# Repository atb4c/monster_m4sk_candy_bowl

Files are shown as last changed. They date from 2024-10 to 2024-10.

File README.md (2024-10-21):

# monster_m4sk_candy_bowl
Using Adafruit's Monster M4SK for a Halloween candy bowl.

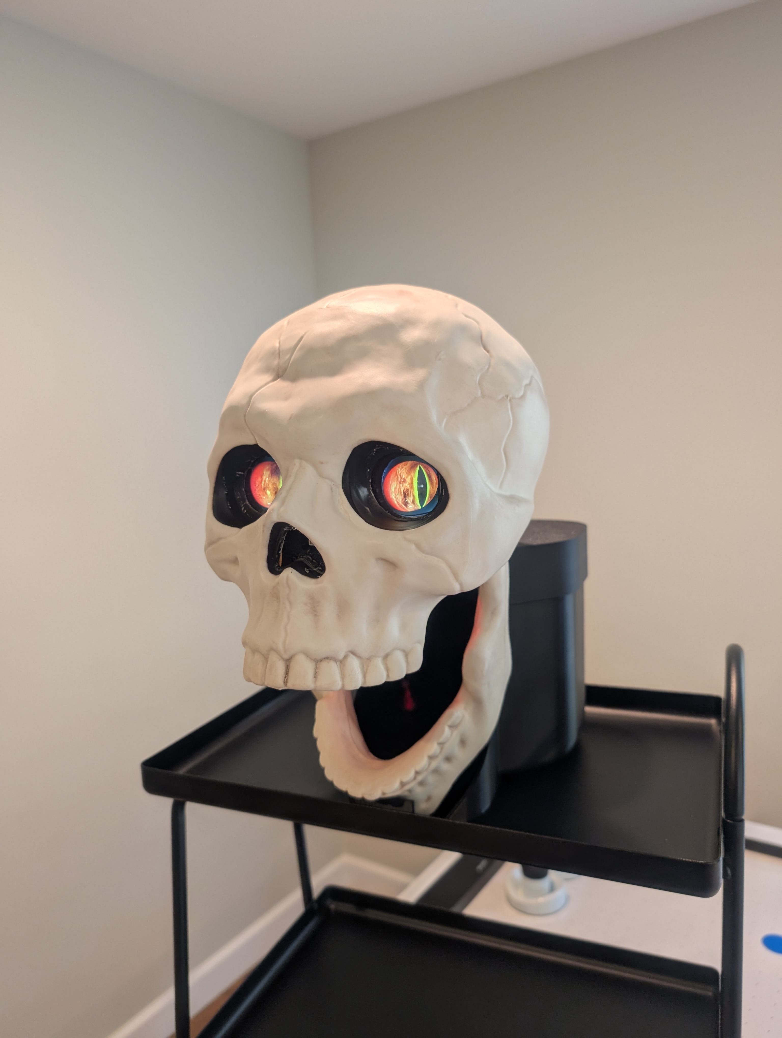
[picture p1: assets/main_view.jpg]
Monster M4SK Candy Bowl

[DEMO VIDEO](assets/demo.mp4)

This was modified from [THIS](https://learn.adafruit.com/monster-m4sk-is-watching-you/overview) project which uses a thermal camera to make the eyes follow you.  I added the ability to play detect when a hand is reached into the candy bowl along with playing audio clips (growling when a person is seen and a roar when a hand is being reached in).

I used [VSCode](https://code.visualstudio.com/) and [platformio](https://platformio.org/), but this could just as easily be done with the Arduino IDE.

Please follow the instructions [HERE](https://learn.adafruit.com/adafruit-monster-m4sk-eyes) to generally setup your Monster M4SK for building from source.

I have included the [EYE Config File](config.eye) I used here as well.

The plastic parts were printed on a BambuLabs P1S.  If you have a similar printer, you should be able to use the 3MF to print everything easily.

## Parts List

1. [Monster M4SK](https://www.adafruit.com/product/4343)
2. [Eye Lenses](https://www.adafruit.com/product/3917)
3. [Eye Connector Cable](https://www.adafruit.com/product/4350)
4. [Lithium Battery](https://www.adafruit.com/product/1781)
5. [Thermal Camera Cable](https://www.adafruit.com/product/3950)
6. [AMG8833 Thermal Camera](https://www.adafruit.com/product/3538)
7. [QT Connector Cable](https://www.adafruit.com/product/4210)
8. [APDS9960 Proximity Sensor](https://www.adafruit.com/product/3595)
9. [Mini-Speaker](https://www.adafruit.com/product/3923)
10. [3-Pin Connector](https://www.adafruit.com/product/3893)
11. [Neopixel LED Stick](https://www.adafruit.com/product/1426)
12. 10-in Skull to mount everything into.  I got mine at a Spirit Halloween, but these look like the same one [LINK1](https://www.tractorsupply.com/tsc/product/red-shed-large-light-up-skull-decoration-2352173?store=1922) [LINK2](https://partyconnexion.com/new-skull-lu-10/)
13. Optional: switch for easy on/off [LINK1](https://www.digikey.com/en/products/detail/e-switch/RA1113112R/3778055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)
14. M2.5 Nylon Screws - I recommend buying [THIS](https://www.adafruit.com/product/3299)

## Instructions

1. Use a dremel tool to remove base of the skull just below where the jow bone connects.
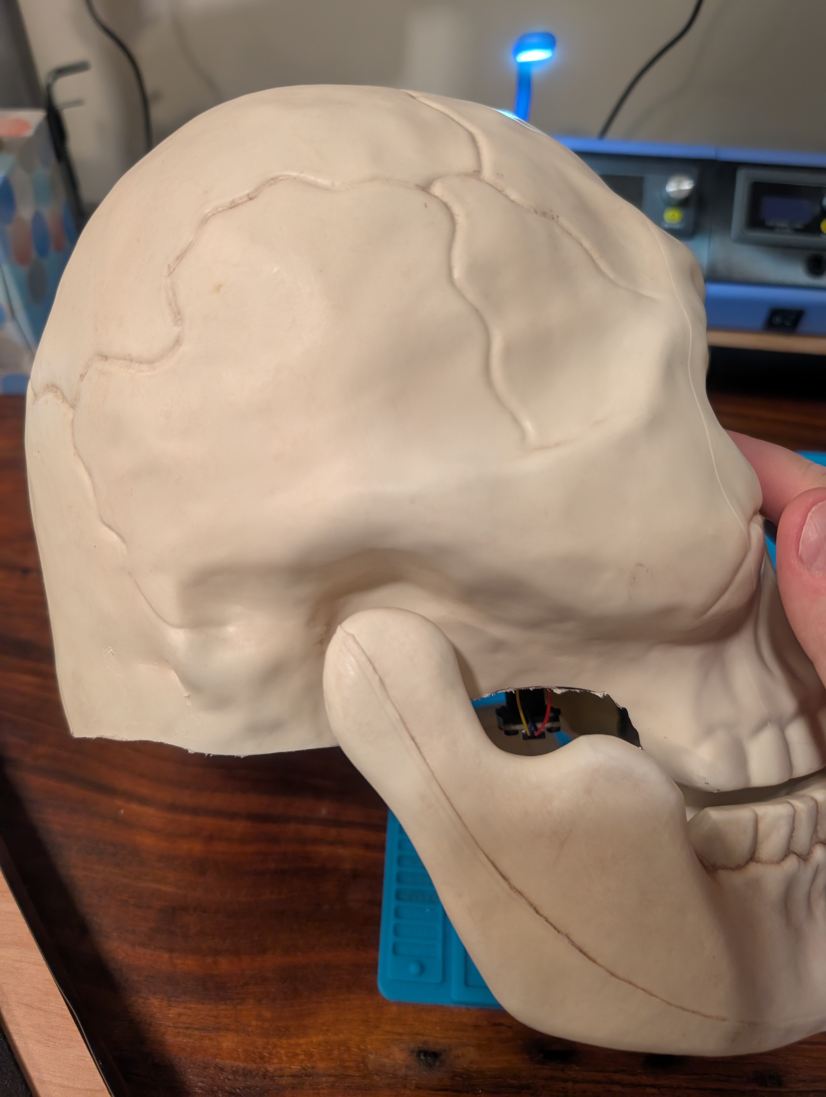
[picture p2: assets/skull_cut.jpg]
skull cutting

2. Once open, remove the light-up electronics from the kull (includes pieces connected to the eies and nose locations).
3. Assemble all the internal plastic pieces as shown here using super glue only if needed after press-fitting
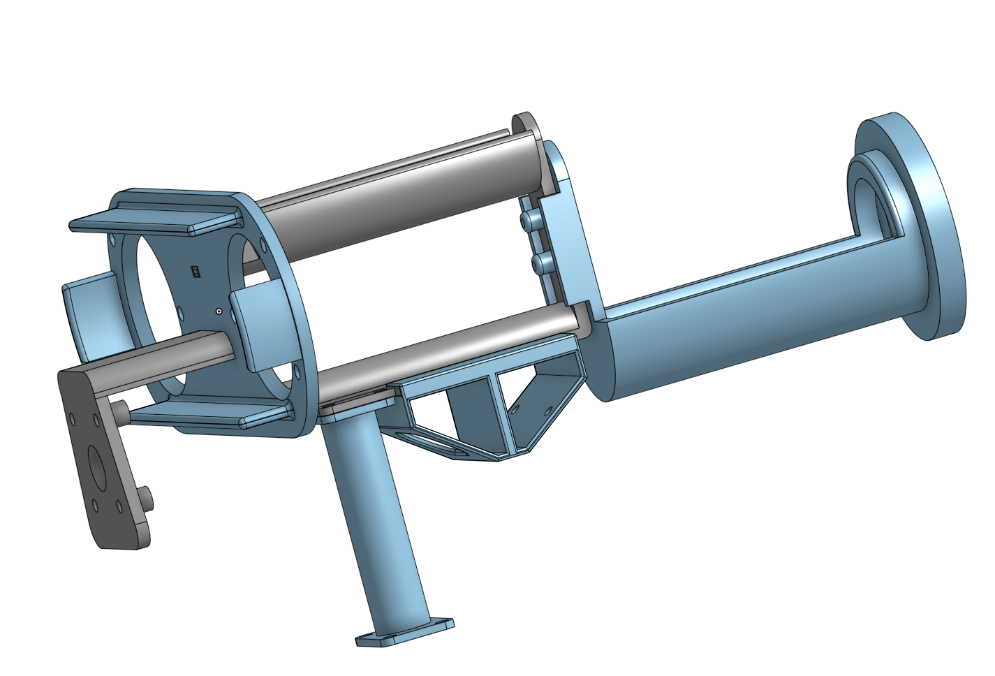
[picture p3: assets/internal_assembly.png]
internal plastic assembly

4. Attach electronics to the internal pieces
5. slide full internal assembly into skull.  It should hold in-place by the front and back pushing against the plastic skull
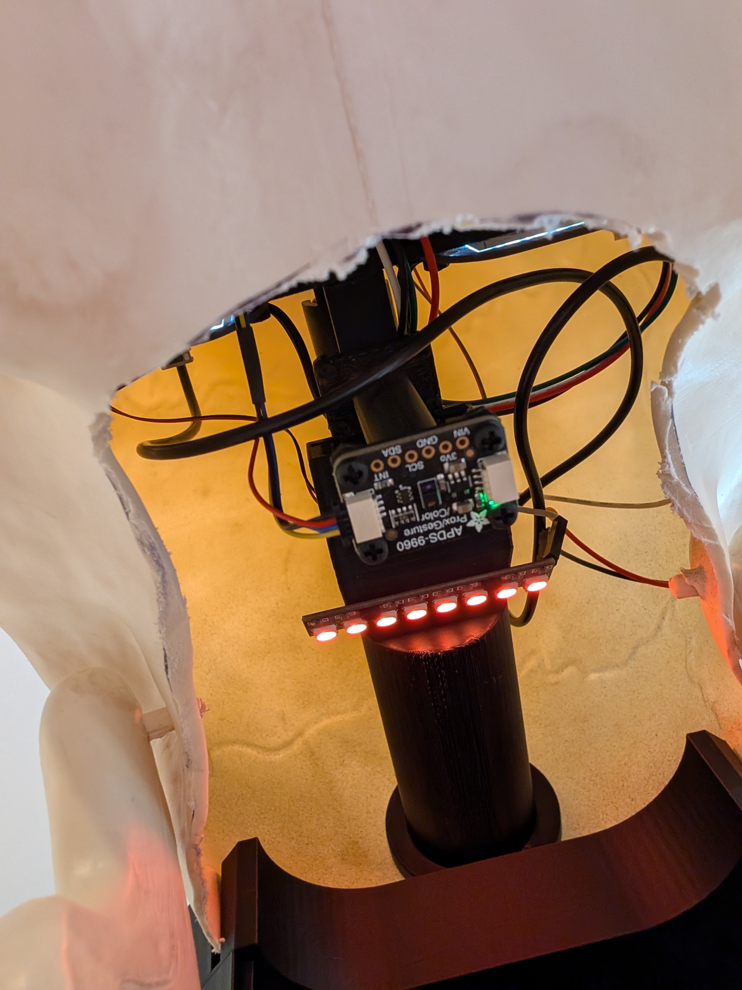
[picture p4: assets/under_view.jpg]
inside

6. Slide the back of the skull into the groove on the bown top
7. slide the skull and bowl top down onto the bowl making sure the jaw bone is open and held in-place by the bottom bracket on the bowl
8. Scare some kids... ;-)

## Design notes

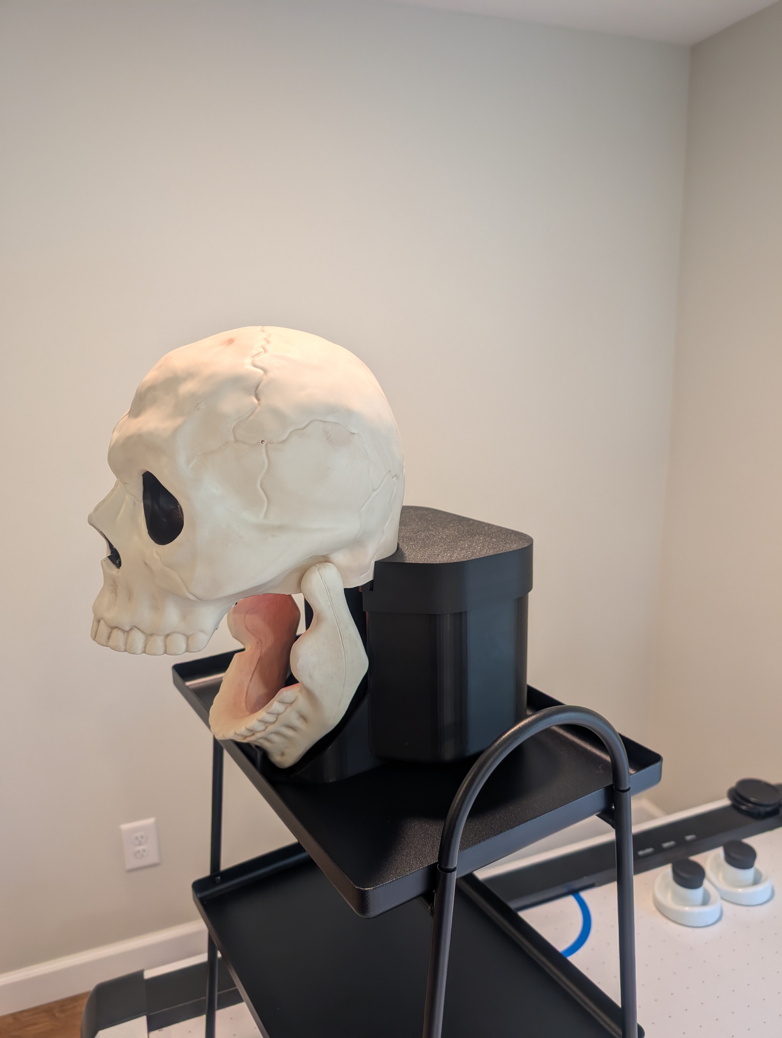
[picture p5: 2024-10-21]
assets/side_view.jpg

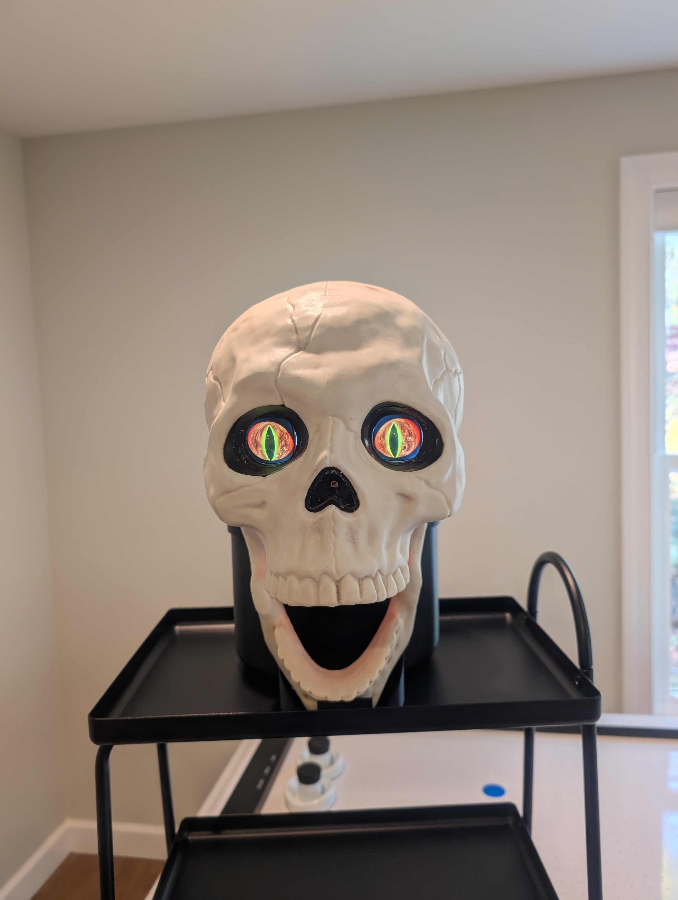
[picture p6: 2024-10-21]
assets/front_view.jpg

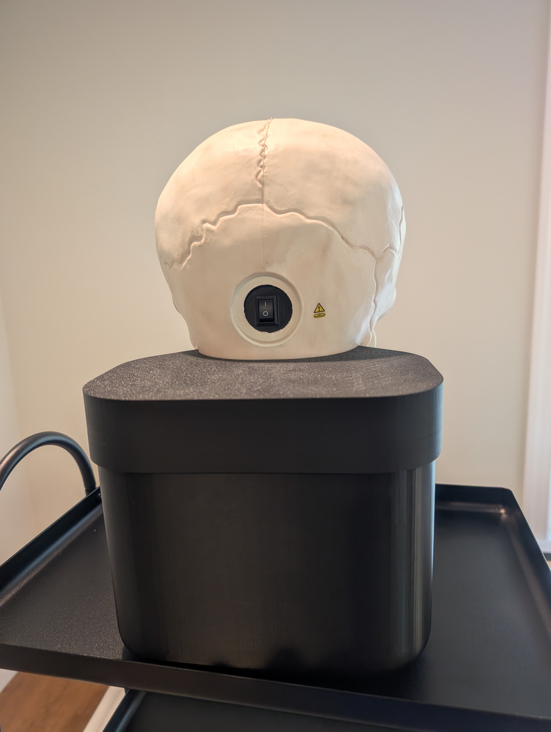
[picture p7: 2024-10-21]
assets/back_view.jpg

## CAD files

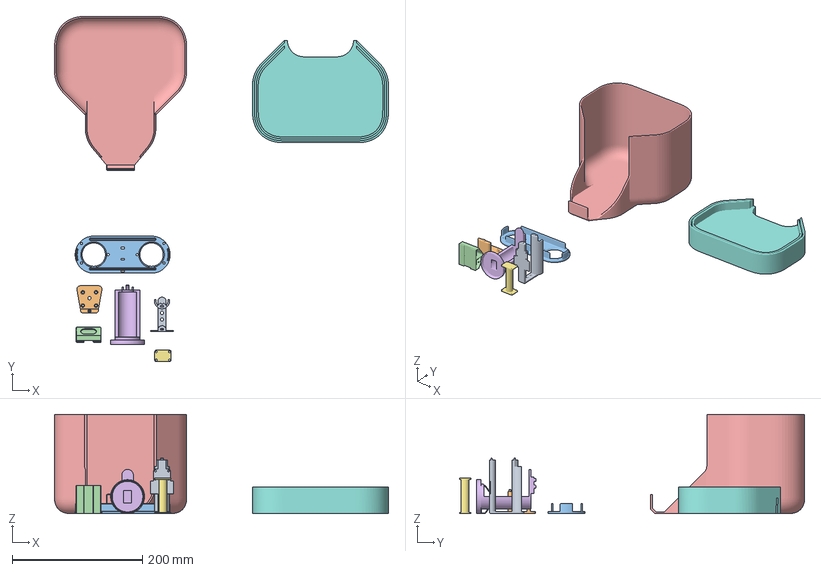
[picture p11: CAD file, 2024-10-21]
mechanicals/3MF/MonsterM4skCandyBowl.3mf
513.3 x 530.9 x 152.4 mm
m4sk_skull_back.stl
m4sk_skull_front (1).stl
m4sk_skull_middle (2).stl
speaker_LED_wedge.stl
bowl (4).stl
back_switch_holder (4).stl
proximity_extension (1).stl
bowl_top (5).stl

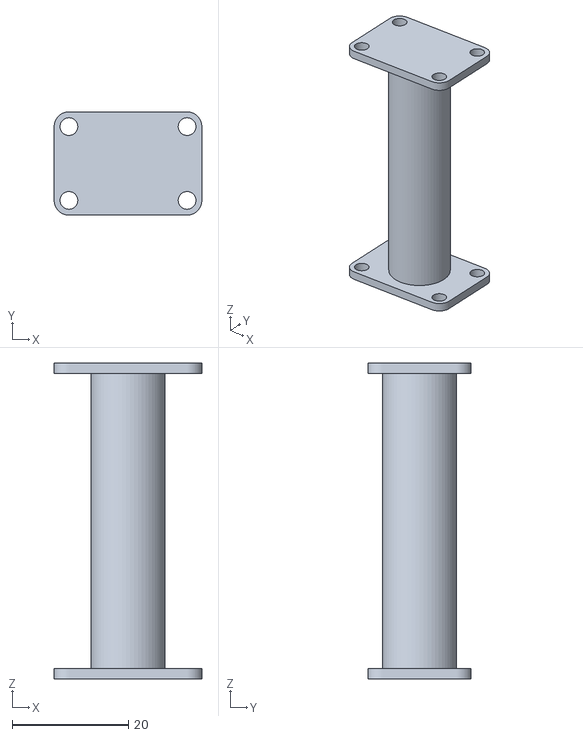
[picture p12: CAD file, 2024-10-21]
mechanicals/STL/proximity_extension.stl
25.4 x 17.8 x 54.4

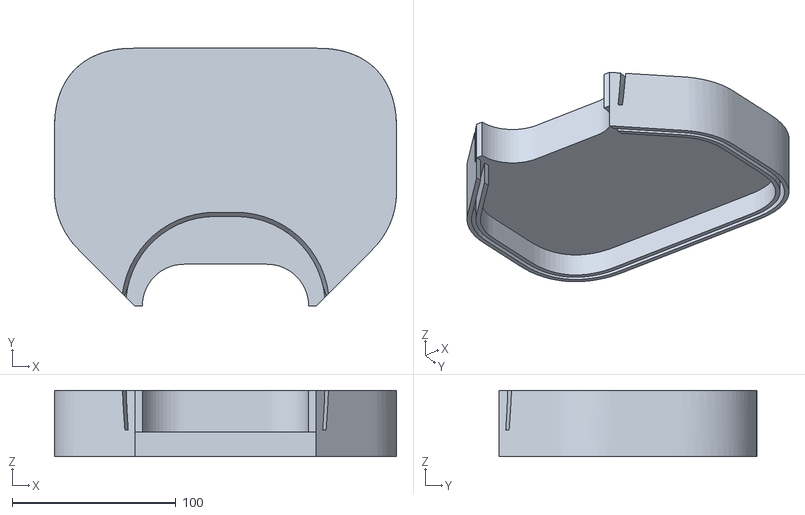
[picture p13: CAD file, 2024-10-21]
mechanicals/STL/bowl_top.stl
209.1 x 157.5 x 40.6

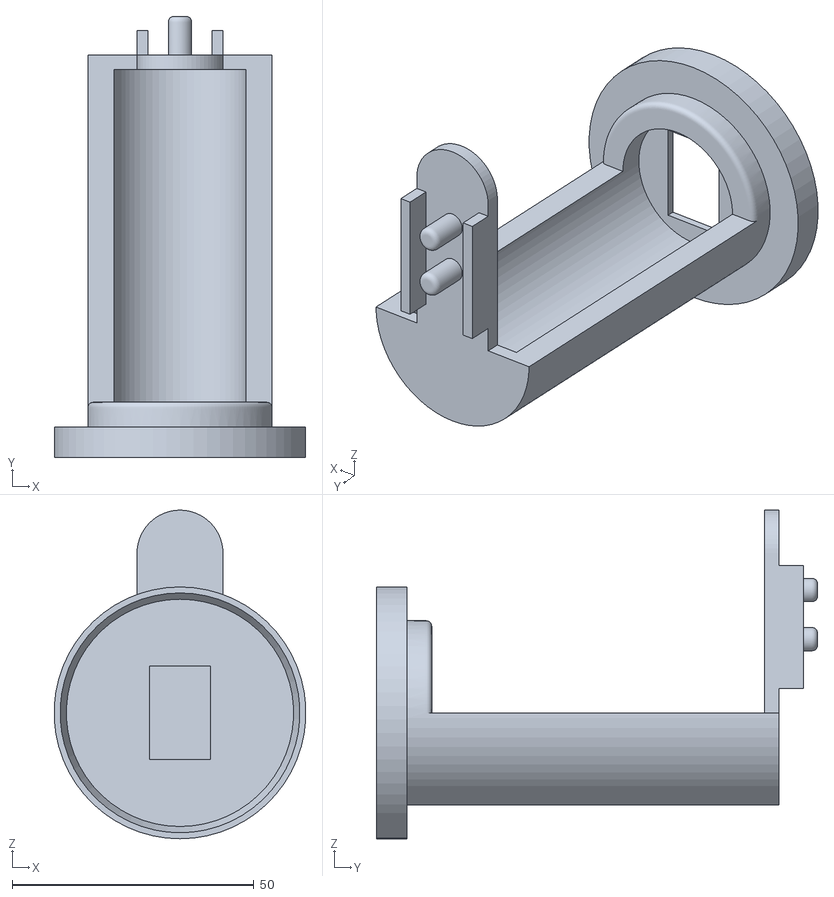
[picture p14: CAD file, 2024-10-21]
mechanicals/STL/back_switch_holder.stl
52.0 x 91.2 x 67.9

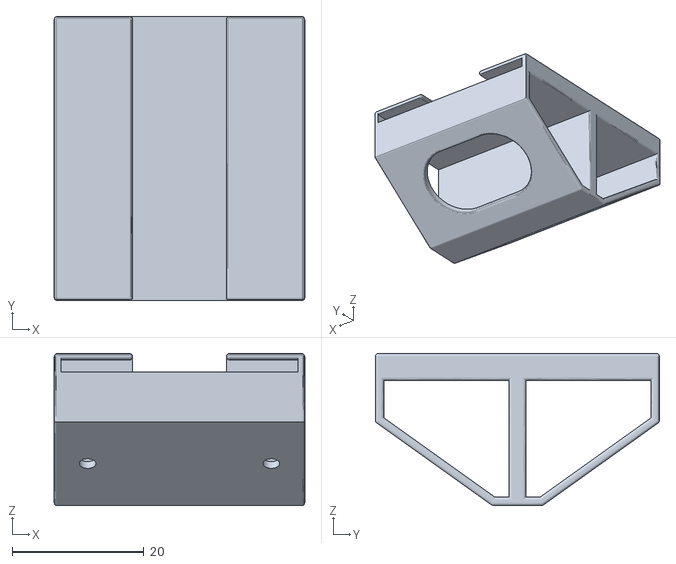
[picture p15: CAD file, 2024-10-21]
mechanicals/STL/speaker_LED_wedge.stl
38.1 x 43.2 x 23.1

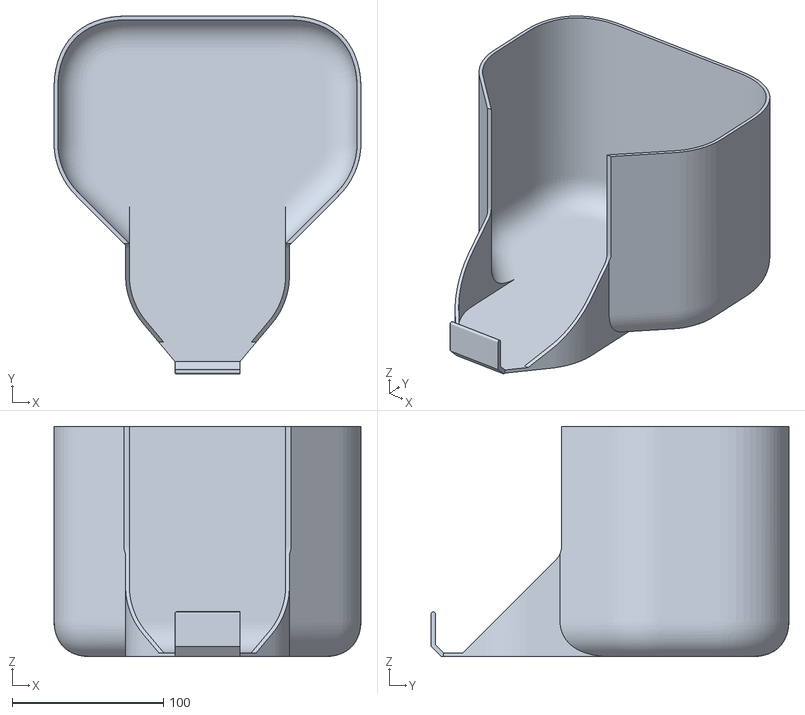
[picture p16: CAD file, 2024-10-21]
mechanicals/STL/bowl.stl
203.2 x 236.9 x 152.4

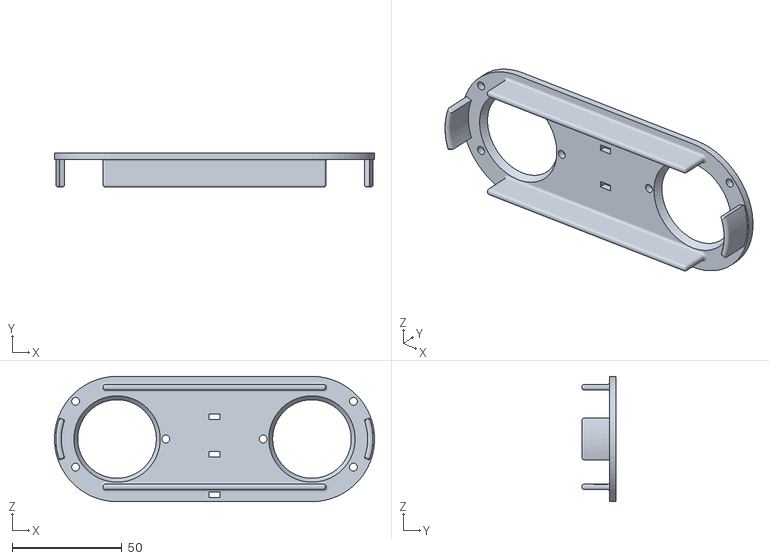
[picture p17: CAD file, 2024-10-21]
mechanicals/STL/m4sk_skull_middle.stl
146.0 x 15.6 x 57.1

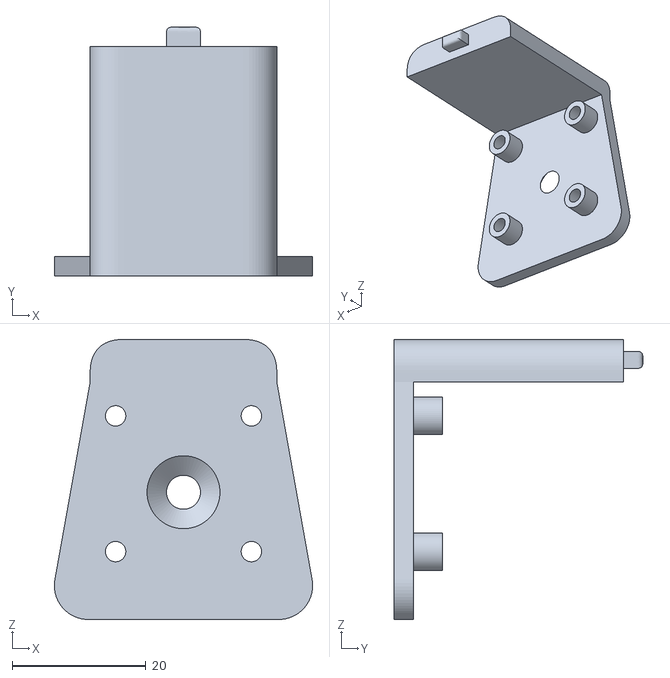
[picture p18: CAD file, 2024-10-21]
mechanicals/STL/m4sk_skull_front.stl
38.7 x 37.2 x 41.9

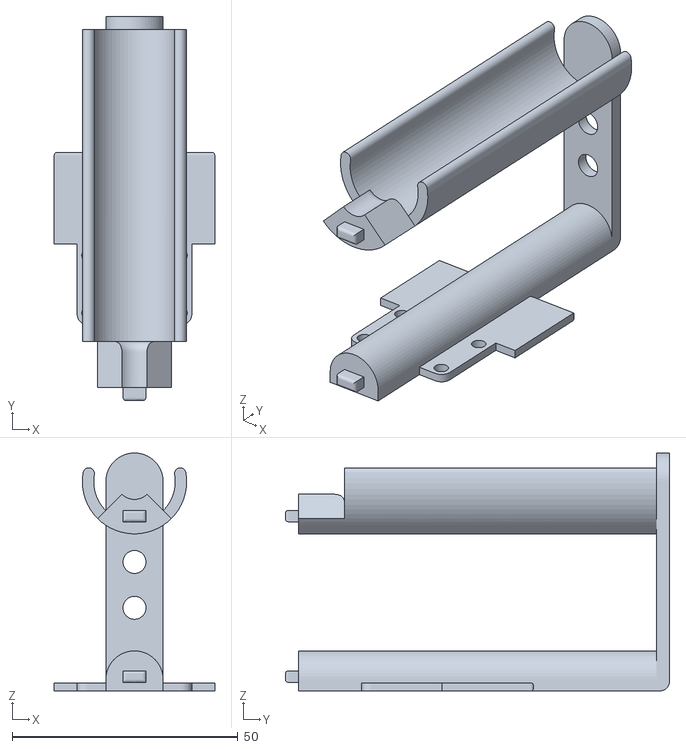
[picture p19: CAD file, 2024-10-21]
mechanicals/STL/m4sk_skull_back.stl
35.6 x 85.1 x 52.7

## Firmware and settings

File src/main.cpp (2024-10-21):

#include <Arduino.h>

// SPDX-FileCopyrightText: 2019 Phillip Burgess for Adafruit Industries
//
// SPDX-License-Identifier: MIT

// Animated eyes for Adafruit MONSTER M4SK and HALLOWING M4 dev boards.
// This code is pretty tightly coupled to the resources of these boards
// (one or two ST7789 240x240 pixel TFTs on separate SPI buses, and a
// SAMD51 microcontroller), and not as generally portable as the prior
// "Uncanny Eyes" project (better for SAMD21 chips or Teensy 3.X and
// 128x128 TFT or OLED screens, single SPI bus).

// IMPORTANT: in rare situations, a board may get "bricked" when running
// this code while simultaneously connected to USB. A quick-flashing status
// LED indicates the filesystem has gone corrupt. If this happens, install
// CircuitPython to reinitialize the filesystem, copy over your eye files
// (keep backups!), then re-upload this code. It seems to happen more often
// at high optimization settings (above -O3), but there's not 1:1 causality.
// The exact cause has not yet been found...possibly insufficient yield()
// calls, or some rare alignment in the Arcada library or USB-handling code.

// LET'S HAVE A WORD ABOUT COORDINATE SYSTEMS before continuing. From an
// outside observer's point of view, looking at the display(s) on these
// boards, the eyes are rendered COLUMN AT A TIME, working LEFT TO RIGHT,
// rather than the horizontal scanline order of Uncanny Eyes and most other
// graphics-heavy code. It was found much easier to animate the eyelids when
// working along this axis. A "column major" display is easily achieved by
// setting the screen(s) to ROTATION 3, which is a 90 degree
// counterclockwise rotation relative to the default. This places (0,0) at
// the BOTTOM-LEFT of the display, with +X being UP and +Y being RIGHT --
// so, conceptually, just swapping axes you have a traditional Cartesian
// coordinate system and trigonometric functions work As Intended, and the
// code tends to "think" that way in most places. Since the rotation is done
// in hardware though...from the display driver's point of view, one might
// think of these as "horizontal" "scanlines," and that the eye is being
// drawn sideways, with a left and right eyelid rather than bottom and top.
// Just mentioning it here because there may still be lingering comments
// and/or variables in the code where I refer to "scanlines" even though
// visually/spatially these are columns. Will do my best to comment local
// coordinate systems in different spots. (Any raster images loaded by
// Adafruit_ImageReader are referenced in typical +Y = DOWN order.)

// Oh also, "left eye" and "right eye" refer to the MONSTER'S left and
// right. From an observer's point of view, looking AT the monster, the
// "right eye" is on the left.

#if !defined(USE_TINYUSB)
  #error "Please select Tools->USB Stack->TinyUSB before compiling"
#endif

#define GLOBAL_VAR
#include "globals.h"

// Global eye state that applies to all eyes (not per-eye):
bool     eyeInMotion = false;
float    eyeOldX, eyeOldY, eyeNewX, eyeNewY;
uint32_t eyeMoveStartTime = 0L;
int32_t  eyeMoveDuration  = 0L;
uint32_t lastSaccadeStop  = 0L;
int32_t  saccadeInterval  = 0L;

// Some sloppy eye state stuff, some carried over from old eye code...
// kinda messy and badly named and will get cleaned up/moved/etc.
uint32_t timeOfLastBlink         = 0L,
         timeToNextBlink         = 0L;
int      xPositionOverMap        = 0;
int      yPositionOverMap        = 0;
uint8_t  eyeNum                  = 0;
uint32_t frames                  = 0;
uint32_t lastFrameRateReportTime = 0;
uint32_t lastLightReadTime       = 0;
float    lastLightValue          = 0.5;
double   irisValue               = 0.5;
int      iPupilFactor            = 42;
uint32_t boopSum                 = 0,
         boopSumFiltered         = 0;
bool     booped                  = false;
int      fixate                  = 7;
uint8_t  lightSensorFailCount    = 0;

// For autonomous iris scaling
#define  IRIS_LEVELS 7
float    iris_prev[IRIS_LEVELS] = { 0 };
float    iris_next[IRIS_LEVELS] = { 0 };
uint16_t iris_frame = 0;

// Callback invoked after each SPI DMA transfer - sets a flag indicating
// the next line of graphics can be issued as soon as its ready.
static void dma_callback(Adafruit_ZeroDMA *dma) {
  // It's possible to assign each DMA channel its own callback function
  // (freeing up a few cycles vs. this channel-to-eye lookup), but it's
  // written this way to scale to as many eyes as needed (up to one per
  // SERCOM if this is ported to something like Grand Central).
  for(uint8_t e=0; e<NUM_EYES; e++) {
    if(dma == &eye[e].dma) {
      eye[e].dma_busy = false;
      return;
    }
  }
}

// >50MHz SPI was fun but just too glitchy to rely on
//#if F_CPU < 200000000
// #define DISPLAY_FREQ   (F_CPU / 2)
// #define DISPLAY_CLKSRC SERCOM_CLOCK_SOURCE_FCPU
//#else
 #define DISPLAY_FREQ   50000000
 #define DISPLAY_CLKSRC SERCOM_CLOCK_SOURCE_100M
//#endif

SPISettings settings(DISPLAY_FREQ, MSBFIRST, SPI_MODE0);

// The time required to issue one scanline (DISPLAY_SIZE pixels x 16 bits) over
// SPI is a known(ish) quantity. The DMA scheduler isn't always perfectly
// deterministic though...especially on startup, as things make their way
// into caches. Very occasionally, something (not known yet) is causing
// SPI DMA to seize up. This condition is pretty easy to check for...
// periodically the code needs to wait on a DMA transfer to finish
// anyway, and we can use the micros() function to determine if it's taken
// considerably longer than expected (a factor of 4 is used - the "4000"
// below, to allow for caching/scheduling fudge). If so, that's our signal
// that something is likely amiss and we take evasive maneuvers, resetting
// the affected DMA channel (DMAbuddy::fix()).
#define DMA_TIMEOUT (uint32_t)((DISPLAY_SIZE * 16 * 4000) / (DISPLAY_FREQ / 1000))

static inline uint16_t readBoop(void) {
  uint16_t counter = 0;
  pinMode(boopPin, OUTPUT);
  digitalWrite(boopPin, HIGH);
  pinMode(boopPin, INPUT);
  while(digitalRead(boopPin) && (++counter < 1000));
  return counter;
}

// Crude error handler. Prints message to Serial Monitor, blinks LED.
void fatal(const char *message, uint16_t blinkDelay) {
  Serial.begin(9600);
  Serial.println(message);
  for(bool ledState = HIGH;; ledState = !ledState) {
    digitalWrite(LED_BUILTIN, ledState);
    delay(blinkDelay);
  }
}

#include <unistd.h> // sbrk() function

uint32_t availableRAM(void) {
  char top;                      // Local variable pushed on stack
  return &top - (char *)sbrk(0); // Top of stack minus end of heap
}

// SETUP FUNCTION - CALLED ONCE AT PROGRAM START ---------------------------

void setup() {
  if(!arcada.arcadaBegin())     fatal("Arcada init fail!", 100);
#if defined(USE_TINYUSB)
  if(!arcada.filesysBeginMSD()) fatal("No filesystem found!", 250);
#else
  if(!arcada.filesysBegin())    fatal("No filesystem found!", 250);
#endif

  // user_setup();

  arcada.displayBegin();

  // Backlight(s) off ASAP, they'll switch on after screen(s) init & clear
  arcada.setBacklight(0);

  DISPLAY_SIZE = min(ARCADA_TFT_WIDTH, ARCADA_TFT_HEIGHT);

  Serial.begin(115200);
  //while(!Serial) yield();

  user_setup();

  Serial.printf("Available RAM at start: %d\n", availableRAM());
  Serial.printf("Available flash at start: %d\n", arcada.availableFlash());
  yield(); // Periodic yield() makes sure mass storage filesystem stays alive

  // No file selector yet. In the meantime, you can override the default
  // config file by holding one of the 3 edge buttons at startup (loads
  // config1.eye, config2.eye or config3.eye instead). Keep fingers clear
  // of the nose booper when doing this...it self-calibrates on startup.
  // DO THIS BEFORE THE SPLASH SO IT DOESN'T REQUIRE A LENGTHY HOLD.
  char *filename = (char *)"config.eye";
 
  uint32_t buttonState = arcada.readButtons();
  if((buttonState & ARCADA_BUTTONMASK_UP) && arcada.exists("config1.eye")) {
    filename = (char *)"config1.eye";
  } else if((buttonState & ARCADA_BUTTONMASK_A) && arcada.exists("config2.eye")) {
    filename = (char *)"config2.eye";
  } else if((buttonState & ARCADA_BUTTONMASK_DOWN) && arcada.exists("config3.eye")) {
    filename = (char *)"config3.eye";
  }

  yield();
  // Initialize display(s)
#if (NUM_EYES > 1)
  eye[0].display = arcada._display;
  eye[1].display = arcada.display2;  
#else
  eye[0].display = arcada.display;
#endif

  // Initialize DMAs
  yield();
  uint8_t e;
  for(e=0; e<NUM_EYES; e++) {
#if (ARCADA_TFT_WIDTH != 160) && (ARCADA_TFT_HEIGHT != 128) // 160x128 is ST7735 which isn't able to deal
    eye[e].spi->setClockSource(DISPLAY_CLKSRC); // Accelerate SPI!
#endif
    eye[e].display->fillScreen(0);
    eye[e].dma.allocate();
    eye[e].dma.setTrigger(eye[e].spi->getDMAC_ID_TX());
    eye[e].dma.setAction(DMA_TRIGGER_ACTON_BEAT);
    eye[e].dptr = eye[e].dma.addDescriptor(NULL, NULL, 42, DMA_BEAT_SIZE_BYTE, false, false);
    eye[e].dma.setCallback(dma_callback);
    eye[e].dma.setPriority(DMA_PRIORITY_0);
    uint32_t spi_data_reg = (uint32_t)eye[e].spi->getDataRegister();
    for(int i=0; i<2; i++) {   // For each of 2 scanlines...
      for(int j=0; j<NUM_DESCRIPTORS; j++) { // For each descriptor on scanline...
        eye[e].column[i].descriptor[j].BTCTRL.bit.VALID    = true;
        eye[e].column[i].descriptor[j].BTCTRL.bit.EVOSEL   = DMA_EVENT_OUTPUT_DISABLE;
        eye[e].column[i].descriptor[j].BTCTRL.bit.BLOCKACT = DMA_BLOCK_ACTION_NOACT;
        eye[e].column[i].descriptor[j].BTCTRL.bit.BEATSIZE = DMA_BEAT_SIZE_BYTE;
        eye[e].column[i].descriptor[j].BTCTRL.bit.DSTINC   = 0;
        eye[e].column[i].descriptor[j].BTCTRL.bit.STEPSEL  = DMA_STEPSEL_SRC;
        eye[e].column[i].descriptor[j].BTCTRL.bit.STEPSIZE = DMA_ADDRESS_INCREMENT_STEP_SIZE_1;
        eye[e].column[i].descriptor[j].DSTADDR.reg         = spi_data_reg;
      }
    }
    eye[e].colNum       = DISPLAY_SIZE; // Force initial wraparound to first column
    eye[e].colIdx       = 0;
    eye[e].dma_busy     = false;
    eye[e].column_ready = false;
    eye[e].dmaStartTime = 0;

    // Default settings that can be overridden in config file
    eye[e].pupilColor        = 0x0000;
    eye[e].backColor         = 0xFFFF;
    eye[e].iris.color        = 0xFF01;
    eye[e].iris.data         = NULL;
    eye[e].iris.filename     = NULL;
    eye[e].iris.startAngle   = (e & 1) ? 512 : 0; // Rotate alternate eyes 180 degrees
    eye[e].iris.angle        = eye[e].iris.startAngle;
    eye[e].iris.mirror       = 0;
    eye[e].iris.spin         = 0.0;
    eye[e].iris.iSpin        = 0;
    eye[e].sclera.color      = 0xFFFF;
    eye[e].sclera.data       = NULL;
    eye[e].sclera.filename   = NULL;
    eye[e].sclera.startAngle = (e & 1) ? 512 : 0; // Rotate alternate eyes 180 degrees
    eye[e].sclera.angle      = eye[e].sclera.startAngle;
    eye[e].sclera.mirror     = 0;
    eye[e].sclera.spin       = 0.0;
    eye[e].sclera.iSpin      = 0;
    eye[e].rotation          = 3;

    // Uncanny eyes carryover stuff for now, all messy:
    eye[e].blink.state = NOBLINK;
    eye[e].blinkFactor = 0.0;
  }

  // SPLASH SCREEN (IF FILE PRESENT) ---------------------------------------

  yield();
  uint32_t startTime, elapsed;
  if (showSplashScreen) {
    showSplashScreen = ((arcada.drawBMP((char *)"/splash.bmp",
                         0, 0, eye[0].display)) == IMAGE_SUCCESS);
    if (showSplashScreen) { // Loaded OK?
      Serial.println("Splashing");
      if (NUM_EYES > 1) {   // Load on other eye too, ignore status
        yield();
        arcada.drawBMP((char *)"/splash.bmp", 0, 0, eye[1].display);
      }
      // Ramp up backlight over 1/2 sec duration
      startTime = millis();
      while ((elapsed = (millis() - startTime)) <= 500) {
        yield();
        arcada.setBacklight(255 * elapsed / 500);
      }
      arcada.setBacklight(255); // To the max
      startTime = millis();     // Note current time for backlight hold later
    }
  }

  // If no splash, or load failed, turn backlight on early so user gets a
  // little feedback, that the board is not locked up, just thinking.
  if (!showSplashScreen) arcada.setBacklight(255);

  // LOAD CONFIGURATION FILE -----------------------------------------------

  loadConfig(filename);

  // LOAD EYELIDS AND TEXTURE MAPS -----------------------------------------
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
void loop() {
  if(++eyeNum >= NUM_EYES) eyeNum = 0; // Cycle through eyes...

  uint8_t  x = eye[eyeNum].colNum;
  uint32_t t = micros();

  // If next column for this eye is not yet rendered...
  if(!eye[eyeNum].column_ready) {
    if(!x) { // If it's the first column...

      // ONCE-PER-FRAME EYE ANIMATION LOGIC HAPPENS HERE -------------------

      // Eye movement
      float eyeX, eyeY;
      if(moveEyesRandomly) {
        int32_t dt = t - eyeMoveStartTime;      // uS elapsed since last eye event
        if(eyeInMotion) {                       // Eye currently moving?
          if(dt >= eyeMoveDuration) {           // Time up?  Destination reached.
            eyeInMotion = false;                // Stop moving
            // The "move" duration temporarily becomes a hold duration...
            // Normally this is 35 ms to 1 sec, but don't exceed gazeMax setting
            uint32_t limit = min(1000000, gazeMax);
            eyeMoveDuration = random(35000, limit); // Time between microsaccades
            if(!saccadeInterval) {              // Cleared when "big" saccade finishes
              lastSaccadeStop = t;              // Time when saccade stopped
              saccadeInterval = random(eyeMoveDuration, gazeMax); // Next in 30ms to 3sec
            }
            // Similarly, the "move" start time becomes the "stop" starting time...
            eyeMoveStartTime = t;               // Save time of event
            eyeX = eyeOldX = eyeNewX;           // Save position
            eyeY = eyeOldY = eyeNewY;
          } else { // Move time's not yet fully elapsed -- interpolate position
            float e  = (float)dt / float(eyeMoveDuration); // 0.0 to 1.0 during move
            e = 3 * e * e - 2 * e * e * e; // Easing function: 3*e^2-2*e^3 0.0 to 1.0
            eyeX = eyeOldX + (eyeNewX - eyeOldX) * e; // Interp X
            eyeY = eyeOldY + (eyeNewY - eyeOldY) * e; // and Y
          }
        } else {                       // Eye is currently stopped
          eyeX = eyeOldX;
          eyeY = eyeOldY;
          if(dt > eyeMoveDuration) {   // Time up?  Begin new move.
            if((t - lastSaccadeStop) > saccadeInterval) { // Time for a "big" saccade
              // r is the radius in X and Y that the eye can go, from (0,0) in the center.
              float r = ((float)mapDiameter - (float)DISPLAY_SIZE * M_PI_2) * 0.75;
              eyeNewX = random(-r, r);
              float h = sqrt(r * r - eyeNewX * eyeNewX);
              eyeNewY = random(-h, h);
              // Set the duration for this move, and start it going.
              eyeMoveDuration = random(83000, 166000); // ~1/12 - ~1/6 sec
              saccadeInterval = 0; // Calc next interval when this one stops
            } else { // Microsaccade
              // r is possible radius of motion, ~1/10 size of full saccade.
              // We don't bother with clipping because if it strays just a little,
              // that's okay, it'll get put in-bounds on next full saccade.
              float r = (float)mapDiameter - (float)DISPLAY_SIZE * M_PI_2;
              r *= 0.07;
              float dx = random(-r, r);
              eyeNewX = eyeX - mapRadius + dx;
              float h = sqrt(r * r - dx * dx);
              eyeNewY = eyeY - mapRadius + random(-h, h);
              eyeMoveDuration = random(7000, 25000); // 7-25 ms microsaccade
            }
            eyeNewX += mapRadius;    // Translate new point into map space
            eyeNewY += mapRadius;
            eyeMoveStartTime = t;    // Save initial time of move
            eyeInMotion      = true; // Start move on next frame
          }
        }
      } else {
        // Allow user code to control eye position (e.g. IR sensor, joystick, etc.)
        float r = ((float)mapDiameter - (float)DISPLAY_SIZE * M_PI_2) * 0.9;
        eyeX = mapRadius + eyeTargetX * r;
        eyeY = mapRadius + eyeTargetY * r;
      }

      // Eyes fixate (are slightly crossed) -- amount is filtered for boops
      int nufix = booped ? 90 : 7;
      fixate = ((fixate * 15) + nufix) / 16;
      // save eye position to this eye's struct so it's same throughout render
      if(eyeNum & 1) eyeX += fixate; // Eyes converge slightly toward center
      else           eyeX -= fixate;
      eye[eyeNum].eyeX = eyeX;
      eye[eyeNum].eyeY = eyeY;

      // pupilFactor? irisValue? TO DO: pick a name and stick with it
      eye[eyeNum].pupilFactor = irisValue;
      // Also note - irisValue is calculated at the END of this function
      // for the next frame (because the sensor must be read when there's
      // no SPI traffic to the left eye)

      // Similar to the autonomous eye movement above -- blink start times
      // and durations are random (within ranges).
      if((t - timeOfLastBlink) >= timeToNextBlink) { // Start new blink?
        timeOfLastBlink = t;
        uint32_t blinkDuration = random(36000, 72000); // ~1/28 - ~1/14 sec
        // Set up durations for both eyes (if not already winking)
        for(uint8_t e=0; e<NUM_EYES; e++) {
          if(eye[e].blink.state == NOBLINK) {
            eye[e].blink.state     = ENBLINK;
            eye[e].blink.startTime = t;
            eye[e].blink.duration  = blinkDuration;
          }
        }
        timeToNextBlink = blinkDuration * 3 + random(4000000);
      }

      float uq, lq; // So many sloppy temp vars in here for now, sorry
      if(tracking) {
        // Eyelids naturally "track" the pupils (move up or down automatically)
        int ix = (int)map2screen(mapRadius - eye[eyeNum].eyeX) + (DISPLAY_SIZE/2), // Pupil position
            iy = (int)map2screen(mapRadius - eye[eyeNum].eyeY) + (DISPLAY_SIZE/2); // on screen
        iy += irisRadius * trackFactor;
        if(eyeNum & 1) ix = DISPLAY_SIZE - 1 - ix; // Flip for right eye
        if(iy > upperOpen[ix]) {
          uq = 1.0;
        } else if(iy < upperClosed[ix]) {
          uq = 0.0;
        } else {
          uq = (float)(iy - upperClosed[ix]) / (float)(upperOpen[ix] - upperClosed[ix]);
        }
        if(booped) {
          uq = 0.9;
          lq = 0.7;
        } else {
          lq = 1.0 - uq;
        }
      } else {
        // If no tracking, eye is FULLY OPEN when not blinking
        uq = 1.0;
        lq = 1.0;
      }
      // Dampen eyelid movements slightly
      // SAVE upper & lower lid factors per eye,
      // they need to stay consistent across frame
      eye[eyeNum].upperLidFactor = (eye[eyeNum].upperLidFactor * 0.6) + (uq * 0.4);
      eye[eyeNum].lowerLidFactor = (eye[eyeNum].lowerLidFactor * 0.6) + (lq * 0.4);

      // Process blinks
      if(eye[eyeNum].blink.state) { // Eye currently blinking?
        // Check if current blink state time has elapsed
        if((t - eye[eyeNum].blink.startTime) >= eye[eyeNum].blink.duration) {
          if(++eye[eyeNum].blink.state > DEBLINK) { // Deblinking finished?
            eye[eyeNum].blink.state = NOBLINK;      // No longer blinking
            eye[eyeNum].blinkFactor = 0.0;
          } else { // Advancing from ENBLINK to DEBLINK mode
            eye[eyeNum].blink.duration *= 2; // DEBLINK is 1/2 ENBLINK speed
            eye[eyeNum].blink.startTime = t;
            eye[eyeNum].blinkFactor = 1.0;
          }
        } else {
          eye[eyeNum].blinkFactor = (float)(t - eye[eyeNum].blink.startTime) / (float)eye[eyeNum].blink.duration;
          if(eye[eyeNum].blink.state == DEBLINK) eye[eyeNum].blinkFactor = 1.0 - eye[eyeNum].blinkFactor;
        }
      }

      // Periodically report frame rate. Really this is "total number of
      // eyeballs drawn." If there are two eyes, the overall refresh rate
      // of both screens is about 1/2 this.
      frames++;
      if(((t - lastFrameRateReportTime) >= 1000000) && t) { // Once per sec.
        Serial.println((frames * 1000) / (t / 1000));
        lastFrameRateReportTime = t;
      }

      // Once per frame (of eye #0), reset boopSum...
      if((eyeNum == 0) && (boopPin >= 0)) {
        boopSumFiltered = ((boopSumFiltered * 3) + boopSum) / 4;
        if(boopSumFiltered > boopThreshold) {
          if(!booped) {
            Serial.println("BOOP!");
          }
          booped = true;
        } else {
          booped = false;
        }
        boopSum = 0;
      }
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

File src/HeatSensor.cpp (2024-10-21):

// SPDX-FileCopyrightText: 2019 teejaydub for Adafruit Industries
//
// SPDX-License-Identifier: MIT

#if 1 // Change to 1 to enable this code (referenced by user_watch.cpp)
// CORRESPONDING LINE IN user_watch.cpp MUST ALSO BE ENABLED!

/* Read the IR sensor and try to figure out where the heat is located. 
*/
#include "HeatSensor.h"

#include <Wire.h>
#include <Adafruit_AMG88xx.h>

Adafruit_AMG88xx amg;

float pixels[AMG88xx_PIXEL_ARRAY_SIZE];

void HeatSensor::setup()
{
    x = 0;
    y = 0;
    magnitude = 0;
    var = 0;

    bool status;
    
    // default settings
    status = amg.begin();
    if (!status) {
        Serial.println("Could not find a valid AMG88xx sensor, check wiring!");
        while (1);
    }

    yield();
    delay(100); // let sensor boot up
}

// Find the approximate X and Y values of the peak temperature in the pixel array,
// along with the magnitude of the brightest spot.
void HeatSensor::find_focus()
{
    amg.readPixels(pixels);
    yield();

    x = 0, y = 0, magnitude = 0, var = 0;
    float minVal = 100, maxVal = 0;
    float sum = 0, sumSq = 0;
    int i = 0;
    for (float yPos = 3.5; yPos > -4; yPos -= 1.0) {
        for (float xPos = 3.5; xPos > -4; xPos -= 1.0) {
            float p = pixels[i];
            x += xPos * p;
            y += yPos * p;
            minVal = min(minVal, p);
            maxVal = max(maxVal, p);
            sum += p;
            sumSq += (p * p);
            i++;
        }
    }

    x = - x / AMG88xx_PIXEL_ARRAY_SIZE / 5.0;
    y = y / AMG88xx_PIXEL_ARRAY_SIZE / 5.0;
    x = max(-1.0, min(1.0, x));
    y = max(-1.0, min(1.0, y));
    magnitude = max(0, min(50, maxVal - 20));
    var = sumSq - ((sum * sum) / i);

    // Report.
#define SERIAL_OUT  4
#if SERIAL_OUT == 1
    // Print raw values
    Serial.print("[");
    for(int i=1; i<=AMG88xx_PIXEL_ARRAY_SIZE; i++){
      Serial.print(pixels[i-1]);
      Serial.print(", ");
      if( i%8 == 0 ) Serial.println();
    }
    Serial.println("]");
    Serial.println();
#endif
#if SERIAL_OUT == 2
    // Print character-graphic array
    const char charPixels[] = " .-*o0#";
    Serial.println("========");
    for (int i = 1; i <= AMG88xx_PIXEL_ARRAY_SIZE; i++) {
      int val = min(5, round(max(0, pixels[i-1] - 20) / 2));
      Serial.print(charPixels[val]);
      if (i % 8 == 0) 
        Serial.println();
    }
    Serial.println();
#endif
#if SERIAL_OUT == 3 || SERIAL_OUT == 2
    // Print coordinates and brightness
    Serial.printf("heat:\tx=%3.1f\ty=%3.1f\tmag=%3.1f\tvar=%3.1f\n", x, y, magnitude, var);
#endif
}

/*
void loop() {
    // Read all the pixels

    // Find the focal point.
    float x, y, magnitude;
    find_focus(x, y, magnitude);

    // Set diagnostic LEDs.
    analogWrite(CENTER_LED, round(max(0, magnitude / 30) * 255));
    analogWrite(RIGHT_LED, round(min(1.0, max(0.0, -x / 3)) * 255));
    analogWrite(LEFT_LED, round(min(1.0, max(0.0, x / 3)) * 255));
    analogWrite(UP_LED, round(min(1.0, max(0.0, y / 3)) * 255));
    analogWrite(DOWN_LED, round(min(1.0, max(0.0, -y / 3)) * 255));

    delay(200);
}
*/
#endif
